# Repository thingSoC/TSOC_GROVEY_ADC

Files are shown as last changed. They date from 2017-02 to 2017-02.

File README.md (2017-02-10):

# TSOC_GROVEY_ADC - thingSoC ADS1115/ADS1015 ADC Module :

**TSOC_GROVEY_ADC** is a four(4) port Analog-to-Digital converter board, an Embedded Module for thingSoC.

The **TSOC_GROVEY_ADC** can operate at either 3.3V or 5V, and can also level translate 3.3V processor bus to 5V Analog peripherals when needed.

The **TSOC_GROVEY_ADC** allows you to connect [thingSoC](http://thingsoc.github.io/), [Mikrobus](http://www.mikroe.com/mikrobus/), 
and/or [Grove System](http://www.seeedstudio.com/blog/2016/03/09/tutorial-intro-to-grove-connectors-for-arduinoraspberry-pi-projects/) 
Modules all at the same time, with any processor module.
This gives you maximum flexiblity for sensor and actuator selection, and reuse. 
When populated with the ADS1115 device it provides 16 bit ADC conversion, and when populated with the ADS1015 device provides 12 bit ADC conversion.

The thingSoC "Grovey Series" was designed as "Everyday Electronics", a no-frills, low cost, approach to modular embedded product design.
thingSoC boards are similar in size to most break-out-boards (BOBs), but feature a standardized stacking pinout, as well as an I2C metadata store (EEPROM)
to indicate what peripherals are installed.

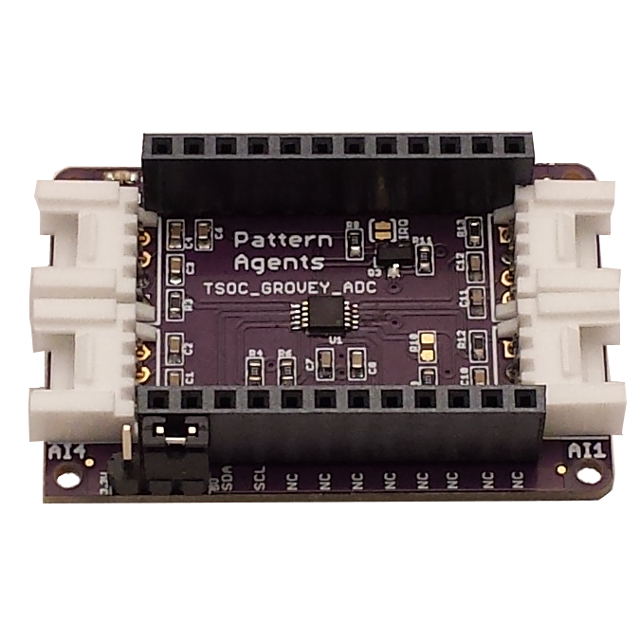
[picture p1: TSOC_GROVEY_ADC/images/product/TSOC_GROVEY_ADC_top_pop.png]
thingSoC TSOC_GROVEY_ADC
[TSOC_GROVEY_ADC](https://github.com/thingSoC/TSOC_GROVEY_ADC)

---------------------------------------

## TSOC_GROVEY_ADC Status <a name="TSOC_GROVEY_ADC_status"/>

**11/06/2016:** 
Revision 1.0 - Initial Layout released to OSHpark

**01/10/2017:**
Revison 2.0 - released to OSHpark

---------------------------------------
## TSOC_GROVEY_ADC Model Images

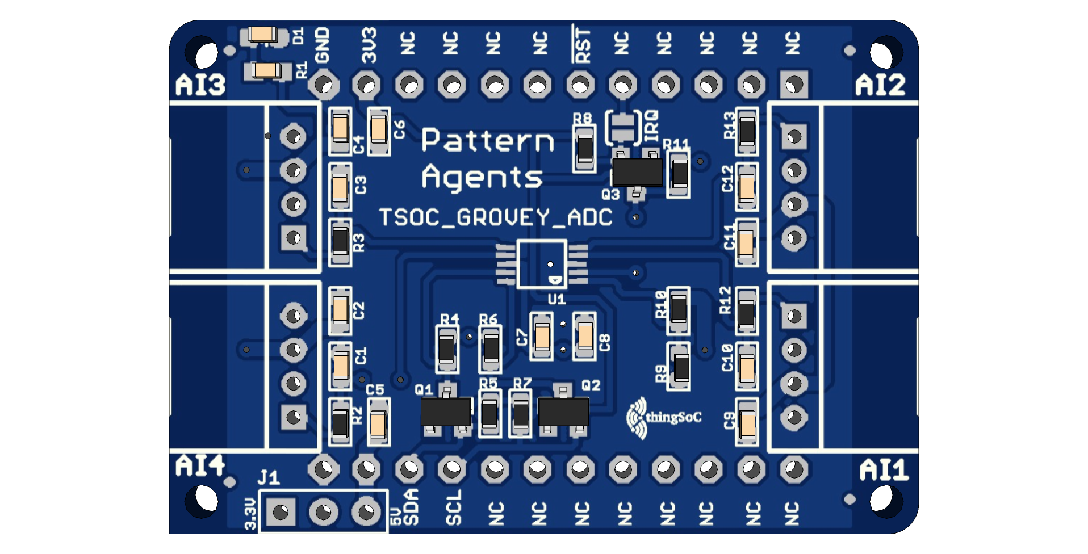
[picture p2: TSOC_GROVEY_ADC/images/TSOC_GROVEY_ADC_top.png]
thingSoC TSOC_GROVEY_ADC
[TSOC_GROVEY_ADC](https://github.com/thingSoC/TSOC_GROVEY_ADC)

[thingSoC TSOC_GROVEY_ADCTSOC_GROVEY_ADC](https://github.com/thingSoC/TSOC_GROVEY_ADC)

---------------------------------------

## TSOC_GROVEY_ADC Documentation Index <a name="TSOC_GROVEY_ADC_documentation_index"/>

[TSOC_GROVEY_ADC Project](http://thingsoc.github.io/projects/TSOC_GROVEY_ADC.html)

[TSOC_GROVEY_ADC Hardware](https://github.com/thingSoC/TSOC_GROVEY_ADC/tree/master/TSOC_GROVEY_ADC/hardware)

---------------------------------------

## thingSoC Documentation Index <a name="thingSoC_documentation_index"/>

[thingSoC Organization Website](http://thingSoC.github.io)

[thingSoC FAQ - Frequently Asked Questions](http://thingsoc.github.io/support/faq.html)

---------------------------------------

[thingSoC 
*thingSoC*](http://thingsoc.github.io)

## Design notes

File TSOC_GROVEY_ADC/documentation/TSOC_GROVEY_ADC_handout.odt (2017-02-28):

thingSoC GROVEY_ADC Board

Thank you for purchasing a TSOC_GROVEY_ADC board!
Please see the Getting Started Guide at :
https://github.com/thingSoC/TSOC_GROVEY_ADC (https://github.com/thingSoC/TSOC_NEOLED)
It has complete instructions and examples to download.

thingSoC GROVEY_ADC Board

Thank you for purchasing a TSOC_GROVEY_ADC board!
Please see the Getting Started Guide at :
https://github.com/thingSoC/TSOC_GROVEY_ADC (https://github.com/thingSoC/TSOC_NEOLED)
It has complete instructions and examples to download.

thingSoC GROVEY_ADC Board

Thank you for purchasing a TSOC_GROVEY_ADC board!
Please see the Getting Started Guide at :
https://github.com/thingSoC/TSOC_GROVEY_ADC (https://github.com/thingSoC/TSOC_NEOLED)
It has complete instructions and examples to download.

thingSoC GROVEY_ADC Board

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

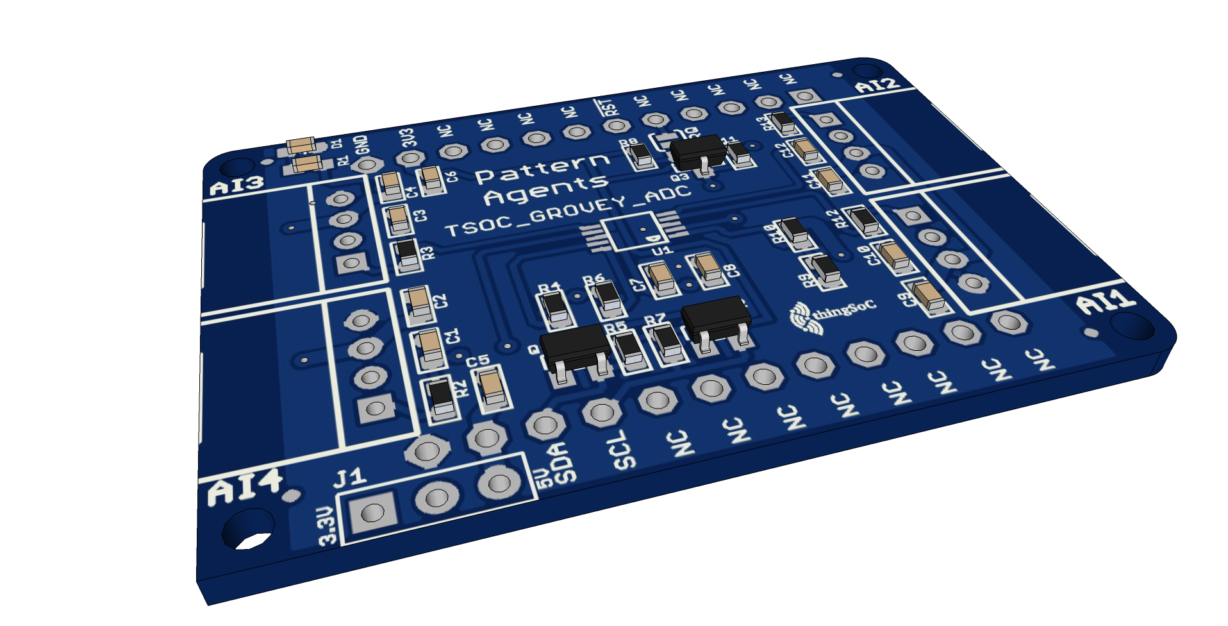
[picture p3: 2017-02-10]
TSOC_GROVEY_ADC/images/TSOC_GROVEY_ADC_iso_raw.png

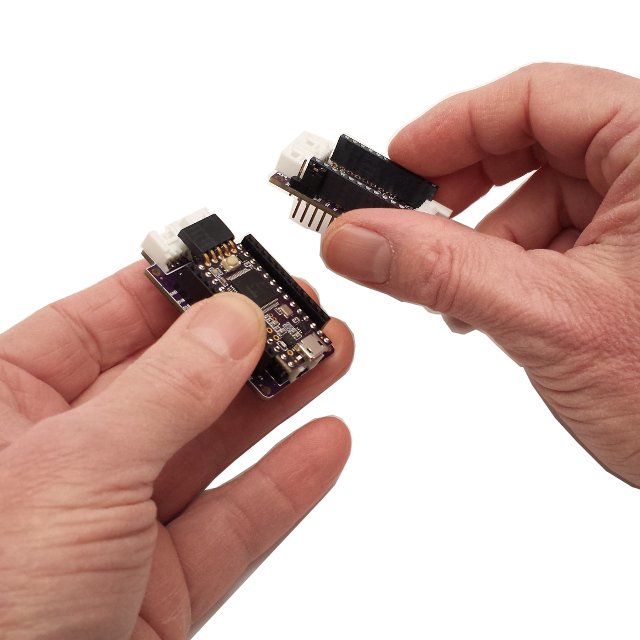
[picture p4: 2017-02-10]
TSOC_GROVEY_ADC/images/product/TSOC_GROVEY_ADC_hand.jpg

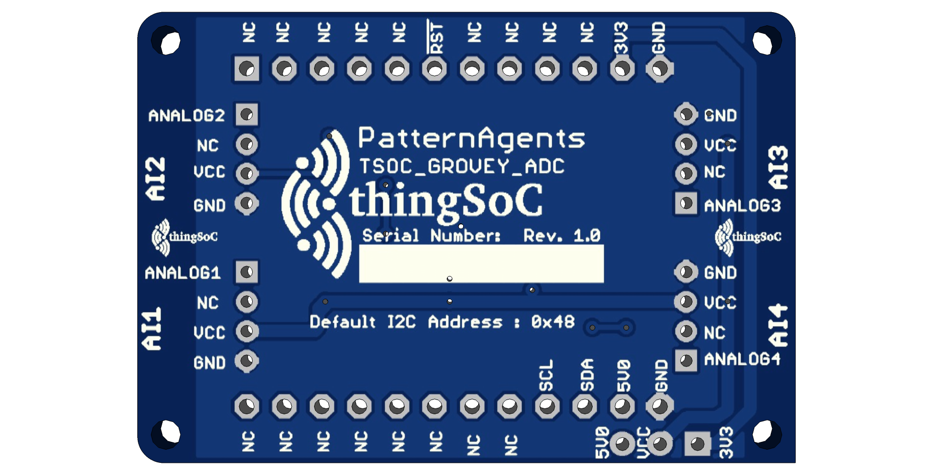
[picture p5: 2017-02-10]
TSOC_GROVEY_ADC/images/TSOC_GROVEY_ADC_bot_raw.png

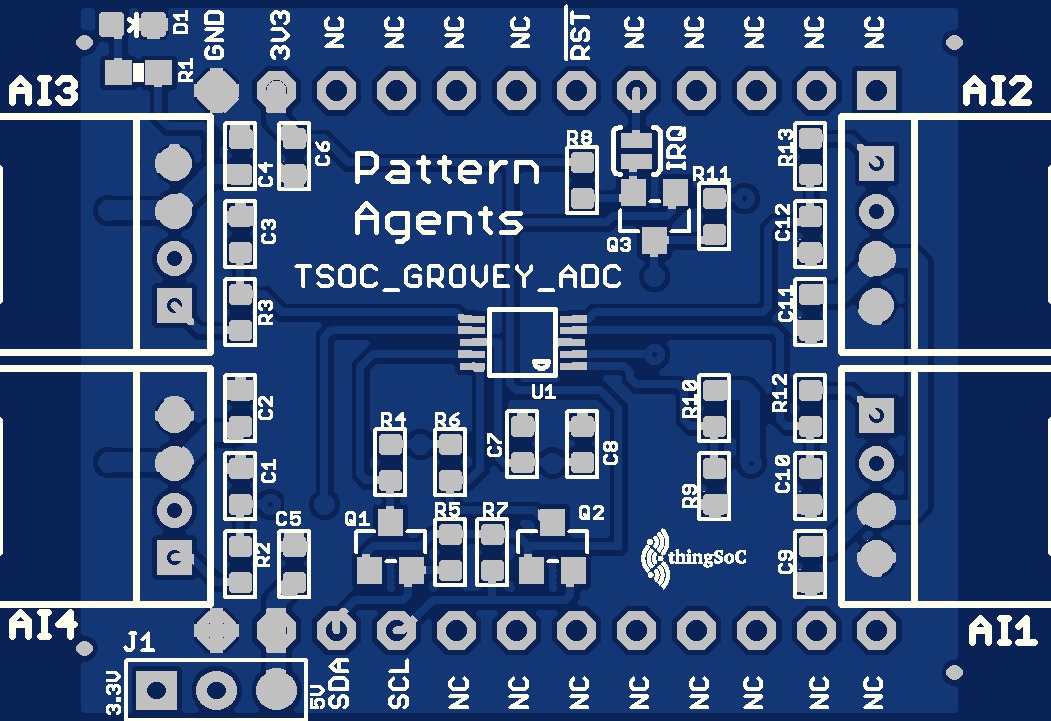
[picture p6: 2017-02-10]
TSOC_GROVEY_ADC/eagleUp/eagleUp_TSOC_GROVEY_ADC_board_top.jpg

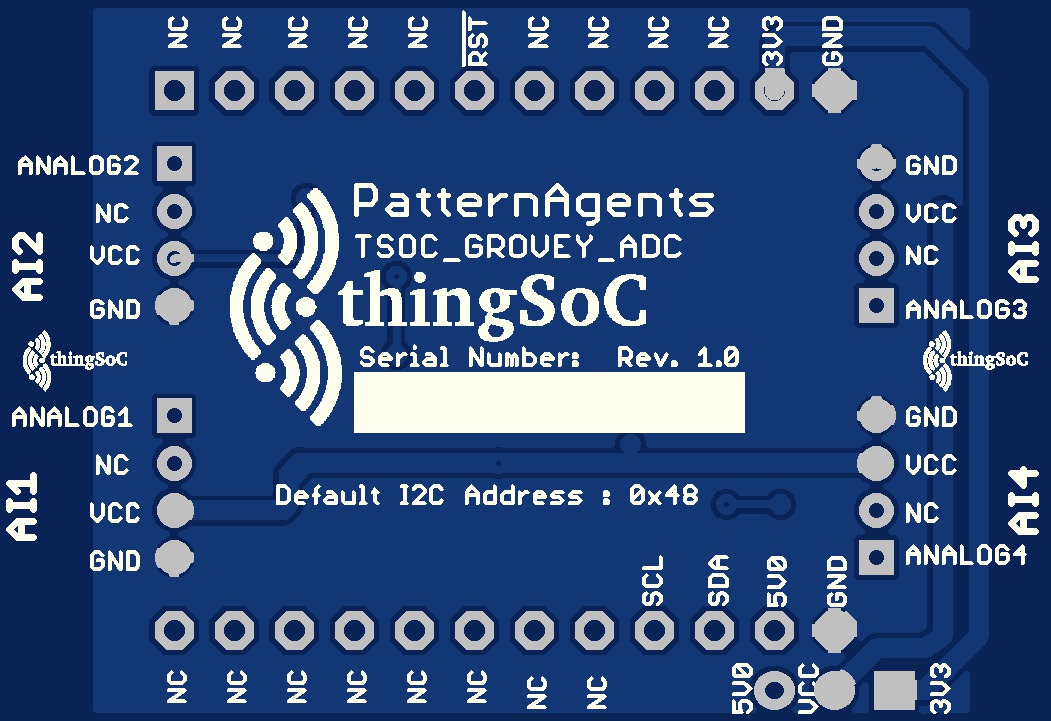
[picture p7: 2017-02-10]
TSOC_GROVEY_ADC/eagleUp/eagleUp_TSOC_GROVEY_ADC_board_bottom.jpg

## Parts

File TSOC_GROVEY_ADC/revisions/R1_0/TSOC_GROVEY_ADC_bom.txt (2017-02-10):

Partlist exported from 
U:/PatternAgents/eagle/TSOC_Modules/TSOC_GROVEY_ADC/TSOC_GROVEY_ADC/revisions/R1_0/TSOC_GROVEY_ADC.sch at 1/29/2017 11:52:49 AM

Qty Value             Device                             Package         Parts                       Description                                          
1   RED               LED0603                            LED-0603        D1                          LEDs                                                 
1   ADS1115IDGST      ADC_ADS1015                        MSOP10          U1                          ADS1015 12-bit 4-Channel I2C ADC
3   BSS138W-7-F       SMD-MOSFET-N-CH-50V-200MA-BSS138W  SOT-23          Q1, Q2, Q3                  305030000                                            
1   1K                RESISTOR_SFE0603-RES               0603-RES        R1                          Resistor                                             
7   10K 1/10W         SMD-RES-10K-5%-1/10W(0603)         R0603           R4, R5, R6, R7, R8, R9, R11 301010293                                            
4   390K              SMD-RES-150K-1%-1/10W(0603)        R0603           R2, R3, R12, R13            301010205                                            
5   100nf             CERAMIC-100NF-50V-10%-X7R(0603)    C0603           C2, C4, C7, C9, C11         302010138                                            
4   1nf               CERAMIC-1NF-50V-5%-C0G(0603)       C0603           C1, C3, C10, C12            302010341                                            
3   1uf               CERAMIC-1UF-25V-10%-X7R(0603)      C0603           C5, C6, C8                  302010139                                            
1   3p-2.54           DIP-BLACK-MALE-HEADER-VERT         H3-2.54         J1                          320020079                                            
4   4P-2.0-90D        GROVE-CONNECTOR-DIP-90D(4P-2.0)    HW4-2.0-90D     AI1, AI2, AI3, AI4          320110034                                            
1                     JMP-2-NO                           JMP-2-NO        IRQ                         Two Terminal Jumper - Normally Open
----------------------------------------------------------------------------
1   DNP               SMD-RES-10K-5%-1/10W(0603)         R0603           R10                         301010293

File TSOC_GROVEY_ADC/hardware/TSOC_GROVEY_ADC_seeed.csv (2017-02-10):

Part/Designator | Manufacture Part Number/Seeed SKU | Quantity
C1, C2, C3, C4, C6, C7 | 302010138 | 6
R8, R9, R10, R11 | 301010299 | 4
R1 | 301010298 | 1
R2, R3, R4, R5, R6, R7, R12, R13, R14, R15 | 301010124 | 10
C5 | 302010013 | 1
I2C1, I2C2, I2C3, I2C4 | 320110034 | 4
J1 | 320020079 | 1
U1 | ADS1115IDGSR | 1
D1 | 304090043 | 1

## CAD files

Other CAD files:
TSOC_GROVEY_ADC/eagleUp/TSOC_GROVEY_ADC.skp

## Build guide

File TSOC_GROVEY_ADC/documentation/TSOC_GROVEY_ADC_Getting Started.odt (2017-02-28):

Welcome to the thingSoC® Grovey ADC

The TSOC_GROVEY_ADC is a four(4) port Analog-to-Digital converter, based on the ADS1015/1115 chip, in an Embedded Module format for the new thingSoC, Internet of Things open source hardware standard.

Getting Started :
The TSOC_GROVEY_ADC provides four (4) Analog-to-Digital ports on four(4) Grove compatible connectors. You can use the TSOC_GROVEY_ADC when :

1. When you need to do input 5.0 Volt level sensors to a 3.3V processor.
2. When you need more resolution than the 3.3V processor can provide.
3. When you need anti-aliasing input conditioning on your analog inputs.

The TSOC_GROVEY_ADC is an open source hardware project from PatternAgents, LLC,
and you are free to download the schematics, layouts, gerbers, BOMs, etc and build your own boards if you wish.

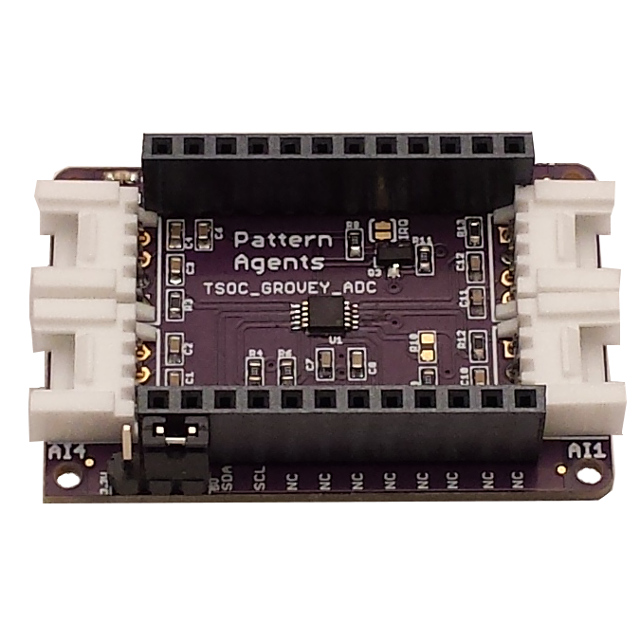
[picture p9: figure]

Safe Handling Precautions :

1) Always remove/unplug all power before inserting or removing peripherals.
2) Always ground yourself by touching a ground point before handling your boards.
3) Use a static safe bag when transporting your TSOC_GROVEY_ADC board.

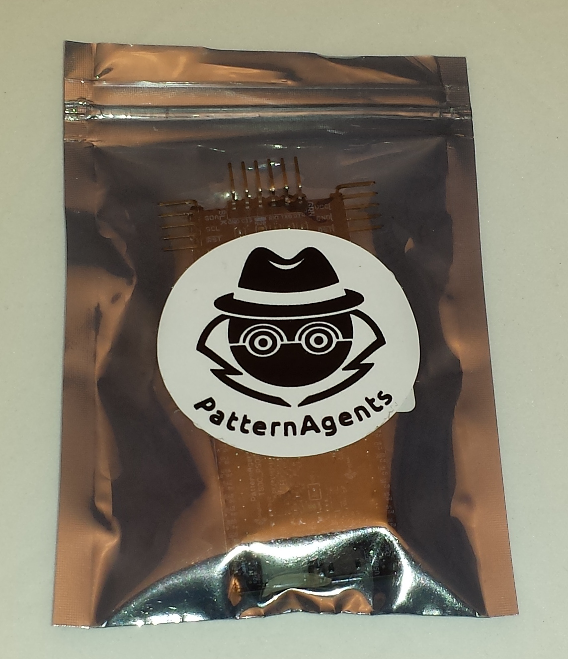
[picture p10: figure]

Adding Grove Peripherals :
The TSOC_GROVEY_ADC board supports Grove peripherals.
1) Grove connectors are polarized, and can only be plugged in one way.


Adding Mikrobus Peripherals :
The TSOC_GROVEY_ADC board supports Grove peripherals and can interoperate with Mikrobus peripherals.

1) Make sure to align the SQUARE/CUT edges of the Mikrobus board together to insure that
the polarity is correct. Push down evenly to seat the boards in the socket.

2) Note that the "stacking pins" are somewhat longer by design, and there will be some
extra space between the boards when using stacking connectors.

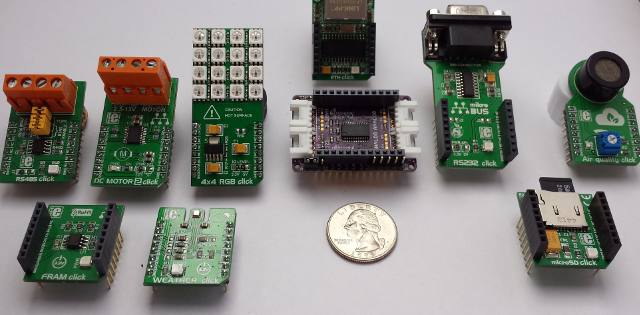
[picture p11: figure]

For more information and examples :

Complete documentation, including schematics, layouts, gerbers, and Bill of Materials (BOM) are available on the thingSoC website at :

https://github.com/thingSoC/TSOC_GROVEY_ADC/tree/master/TSOC_GROVEY_ADC (https://github.com/thingSoC/TSOC_PSoC4L/tree/master/TSOC_PSoC4L)

There is also a project Wiki available for asking questions and more information at :

https://github.com/thingSoC/TSOC_GROVEY_ADC/wiki (https://github.com/thingSoC/TSOC_PSoC4L/wiki)

thingSoC® Grovey ADC Features :

The TSOC_GROVEY_ADC is a low cost, embeddable module featuring an NXP PCA9546A device :

- ADS1015 (12 bits) or ADS1115 (16 bits)
- 0 Hz to 400KHz I2C Bus Speed
- 3.3 Volt or 5.0 Volt operation
- Optional Active Low Reset Line
- Low Standby current
- Builtin ESD protection
- ADC (4 Channels)
- Power LED
- thingSoC Compliant Module
- Mikrobus Compatible Module (http://www.mikroe.com/mikrobus/)
- Support SeeedStudio Grove Peripherals

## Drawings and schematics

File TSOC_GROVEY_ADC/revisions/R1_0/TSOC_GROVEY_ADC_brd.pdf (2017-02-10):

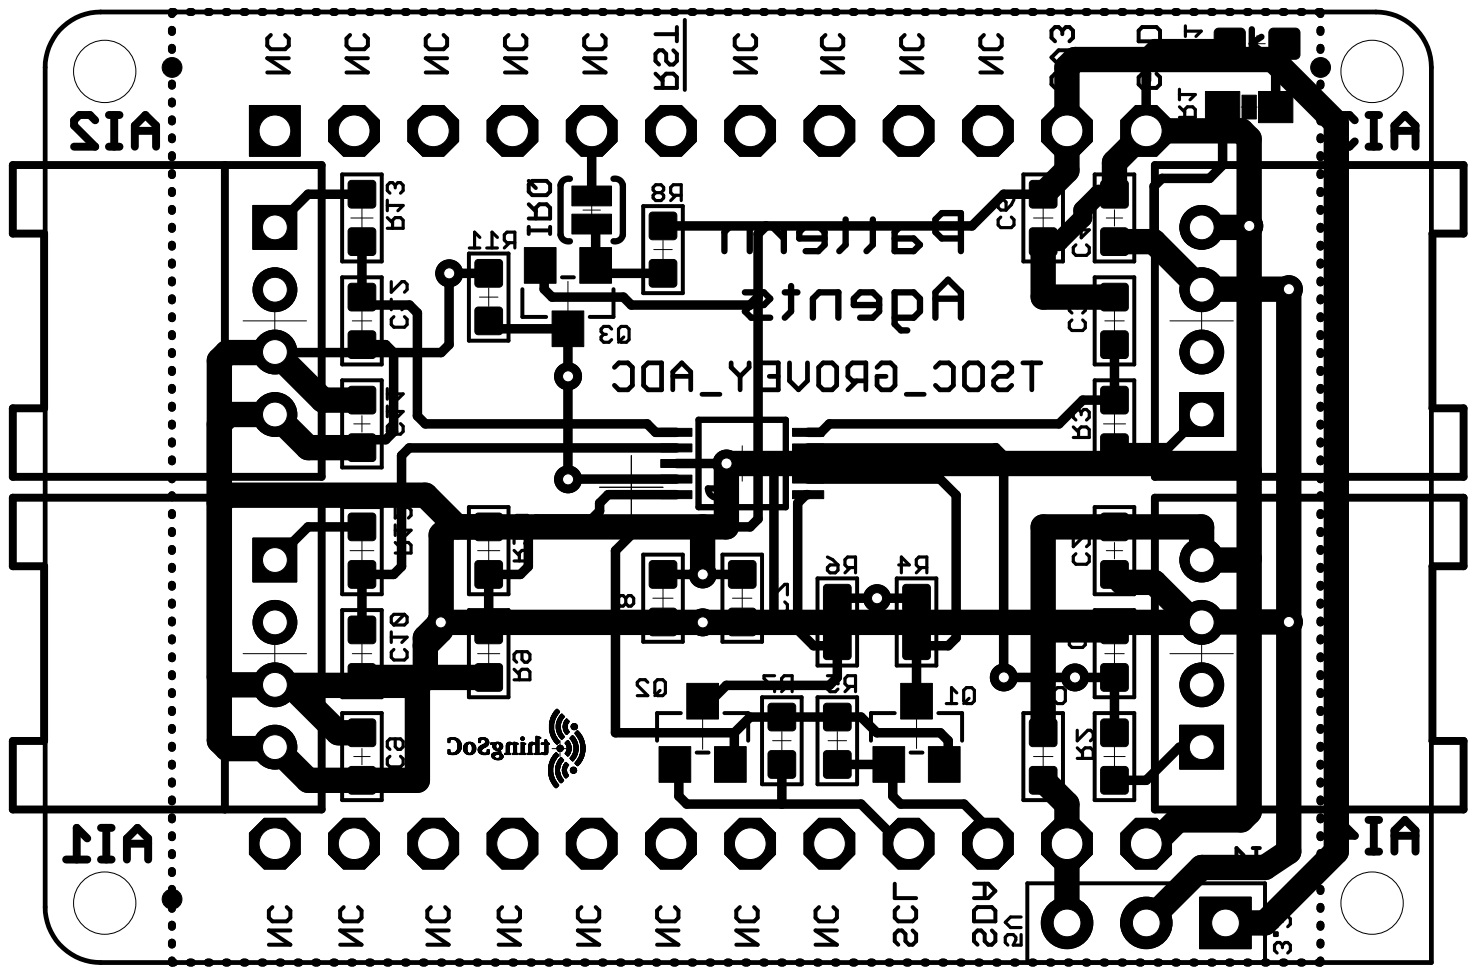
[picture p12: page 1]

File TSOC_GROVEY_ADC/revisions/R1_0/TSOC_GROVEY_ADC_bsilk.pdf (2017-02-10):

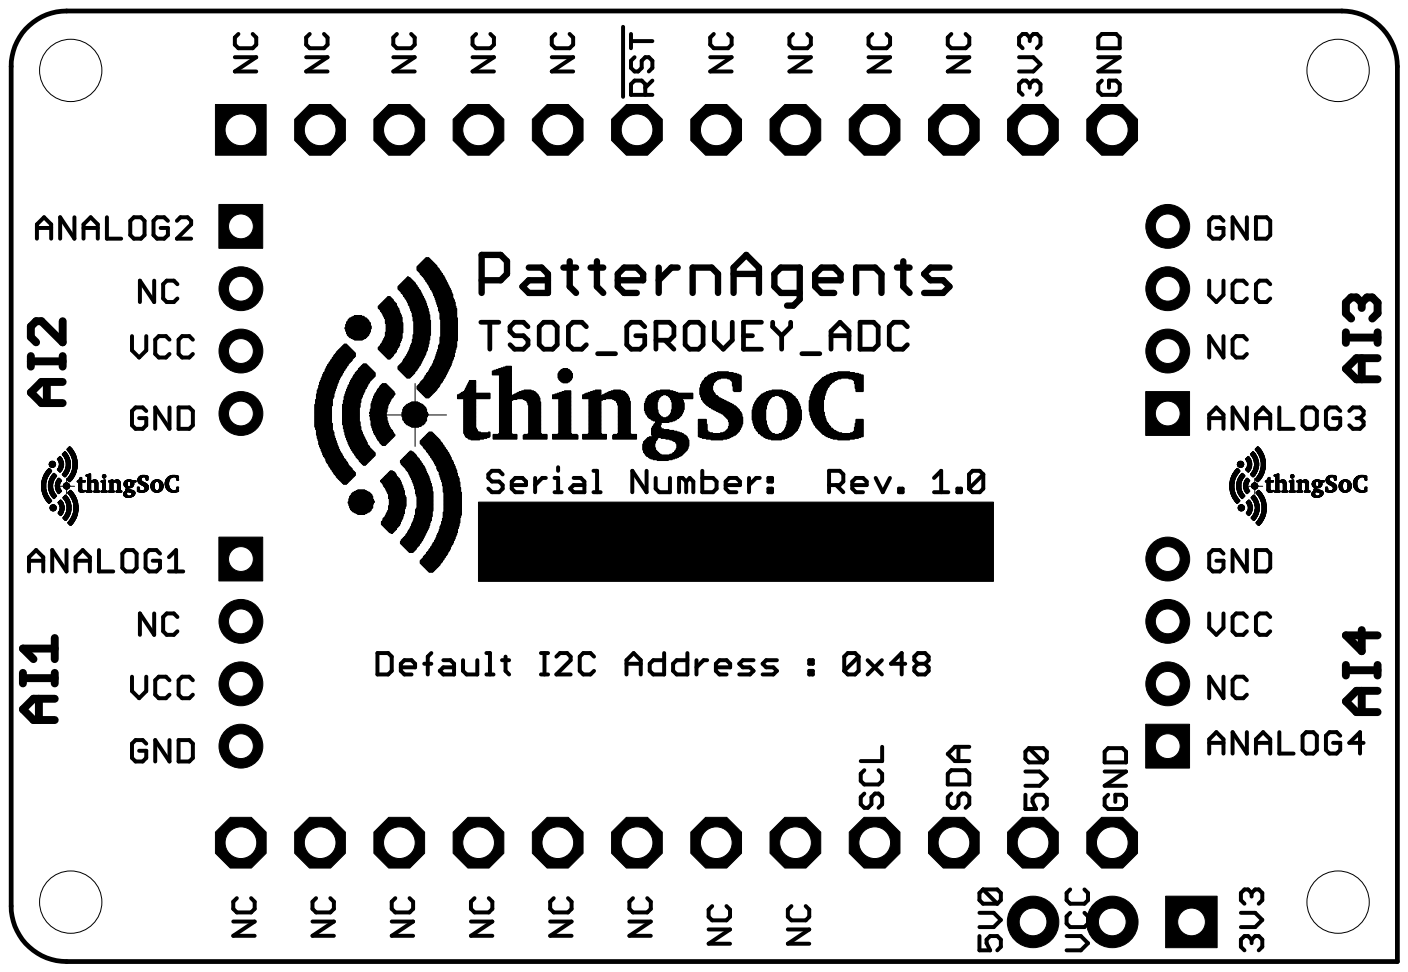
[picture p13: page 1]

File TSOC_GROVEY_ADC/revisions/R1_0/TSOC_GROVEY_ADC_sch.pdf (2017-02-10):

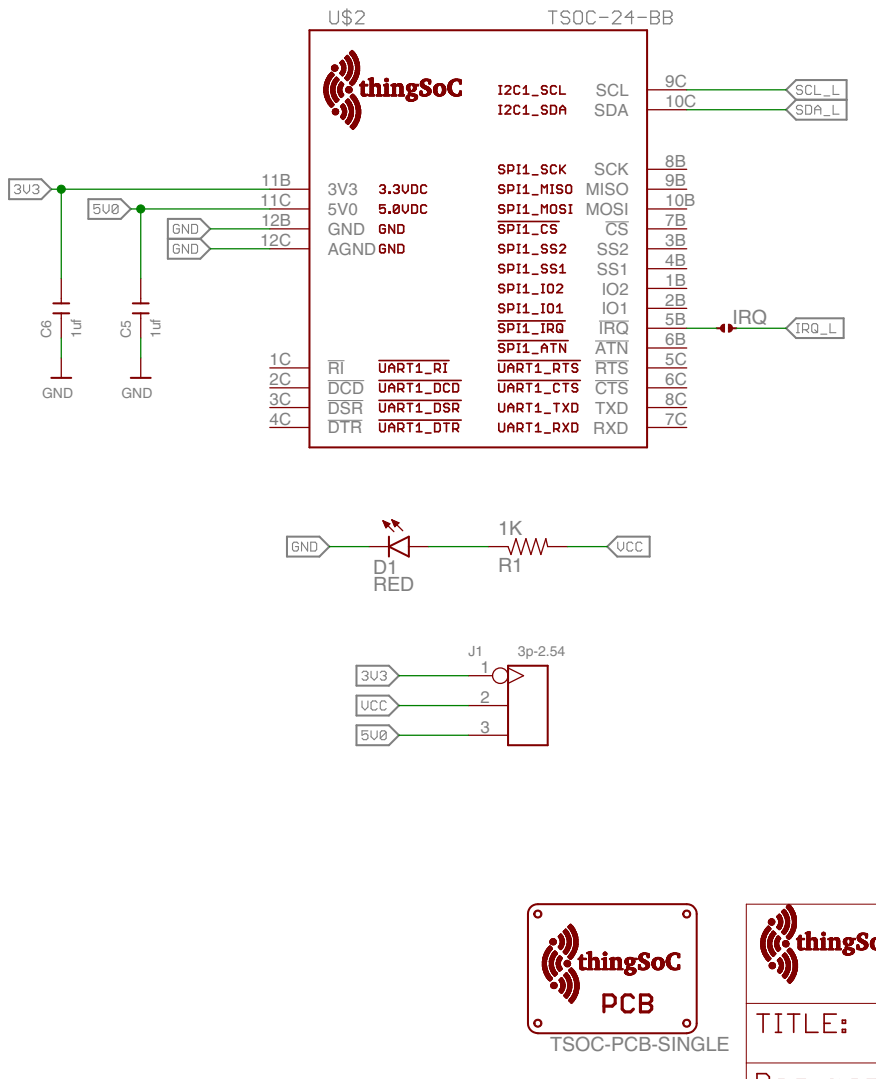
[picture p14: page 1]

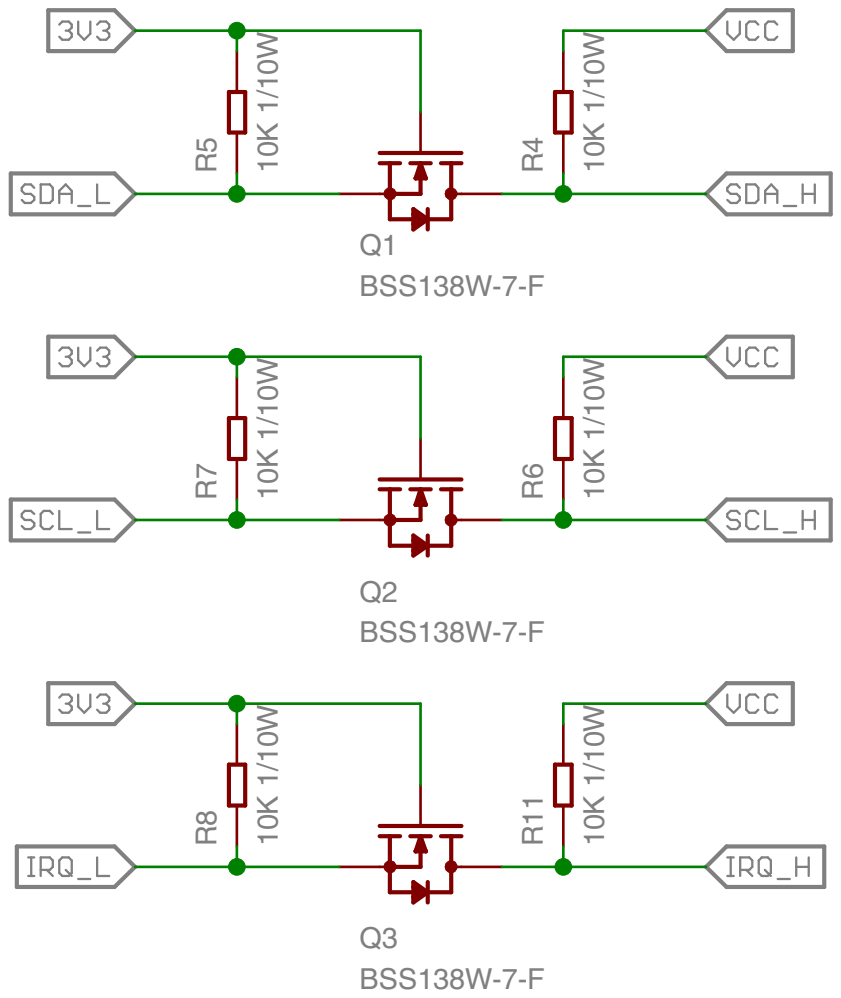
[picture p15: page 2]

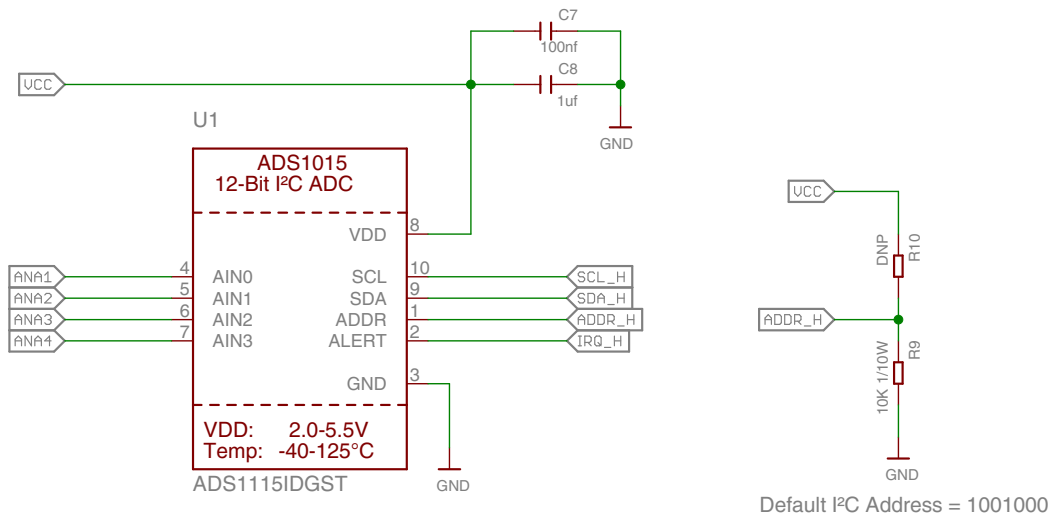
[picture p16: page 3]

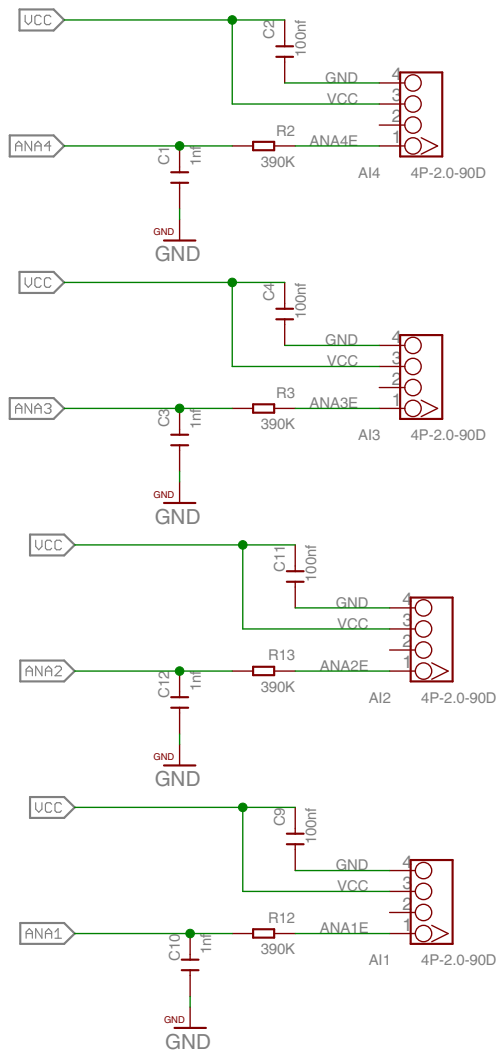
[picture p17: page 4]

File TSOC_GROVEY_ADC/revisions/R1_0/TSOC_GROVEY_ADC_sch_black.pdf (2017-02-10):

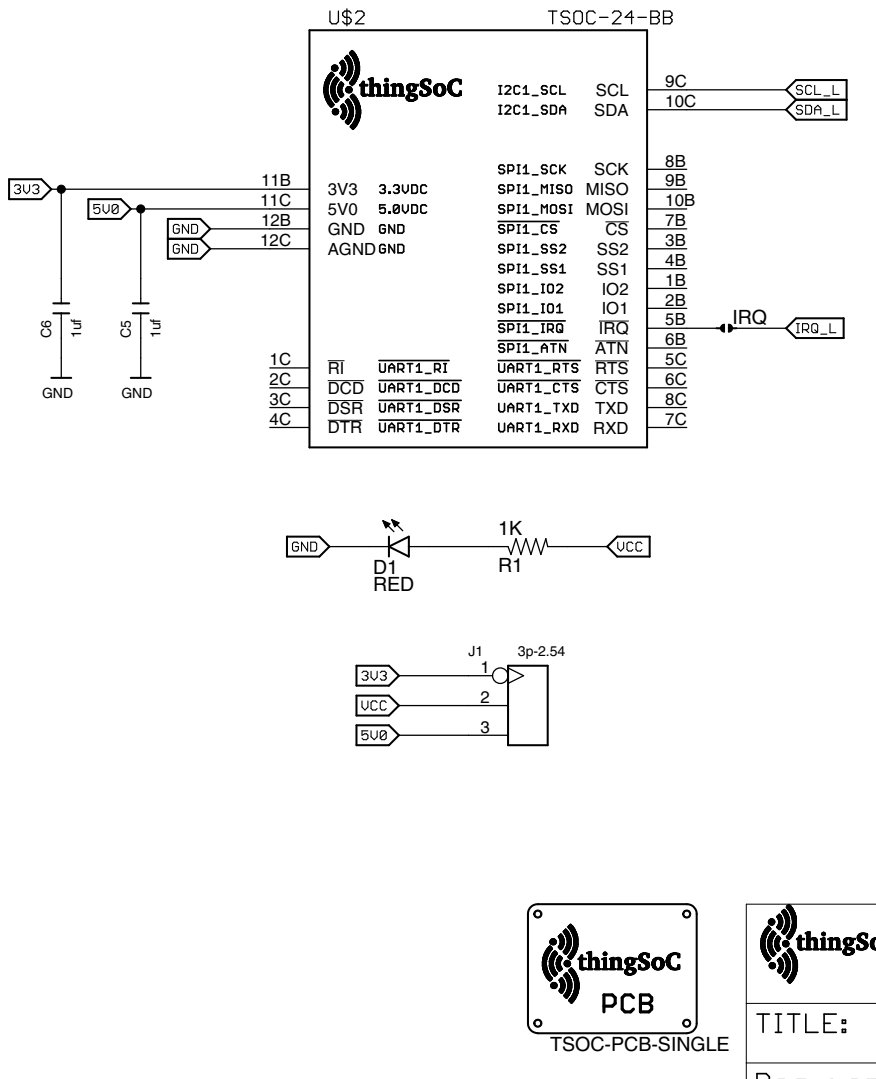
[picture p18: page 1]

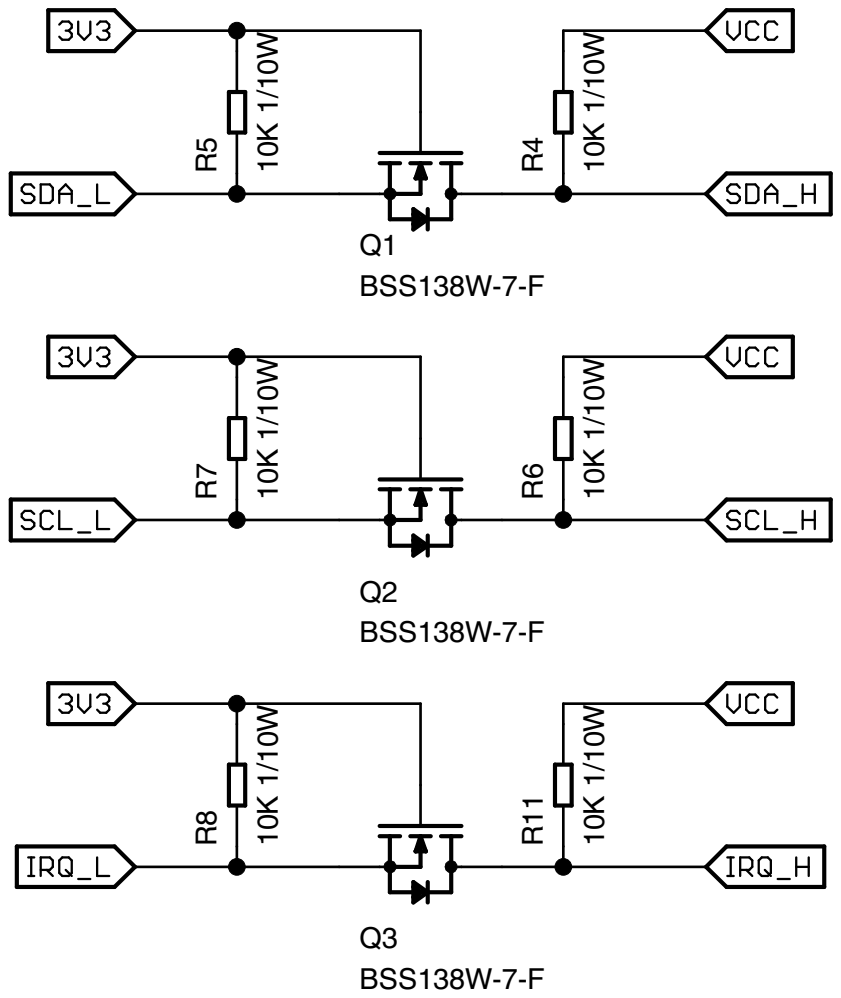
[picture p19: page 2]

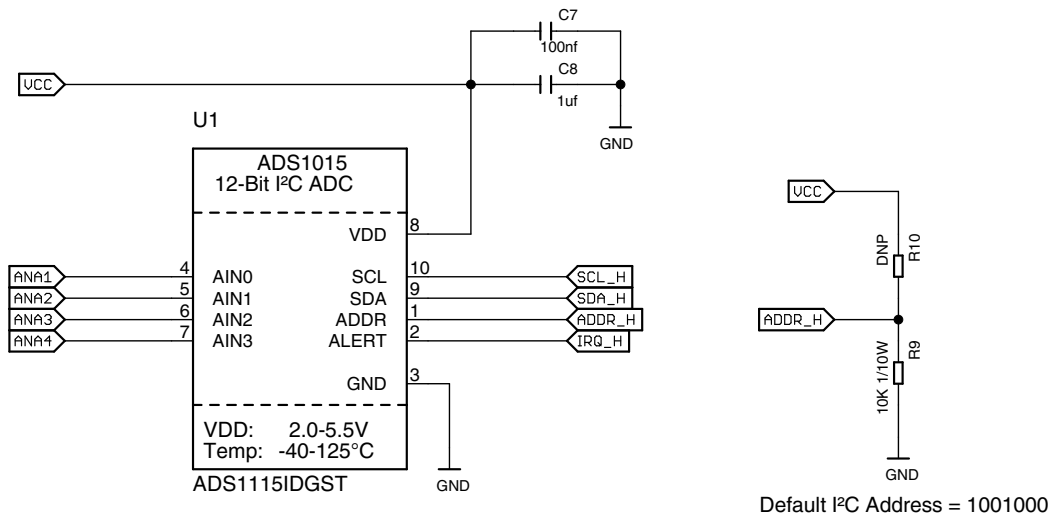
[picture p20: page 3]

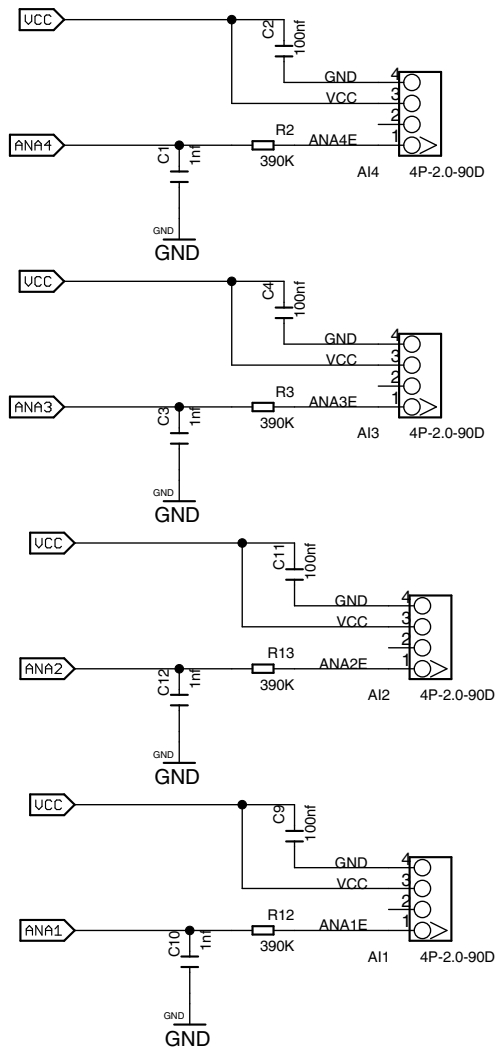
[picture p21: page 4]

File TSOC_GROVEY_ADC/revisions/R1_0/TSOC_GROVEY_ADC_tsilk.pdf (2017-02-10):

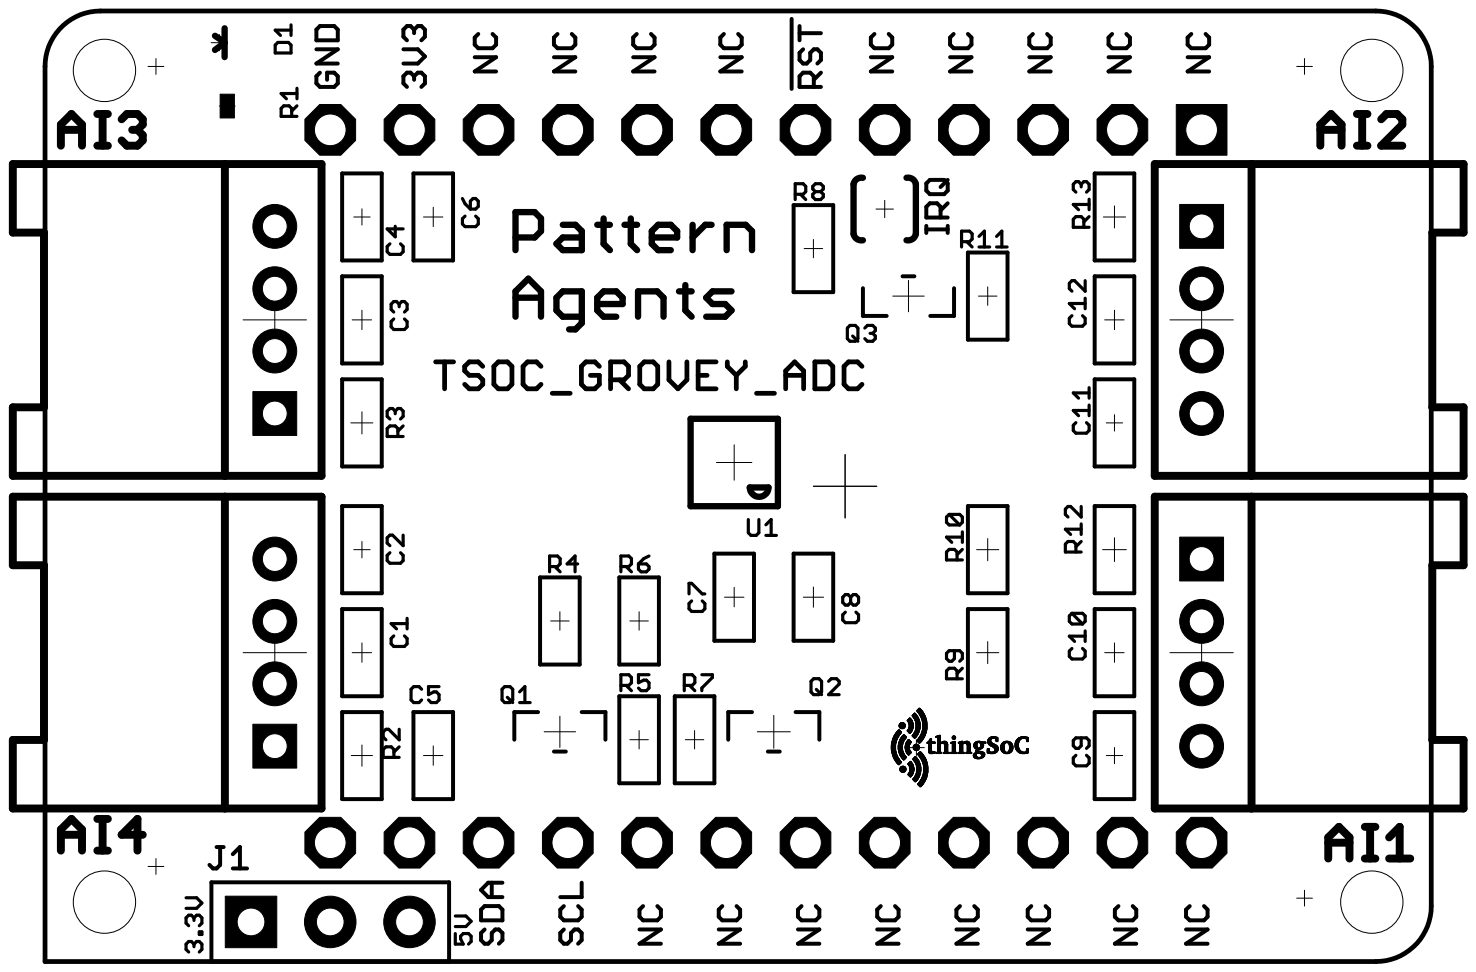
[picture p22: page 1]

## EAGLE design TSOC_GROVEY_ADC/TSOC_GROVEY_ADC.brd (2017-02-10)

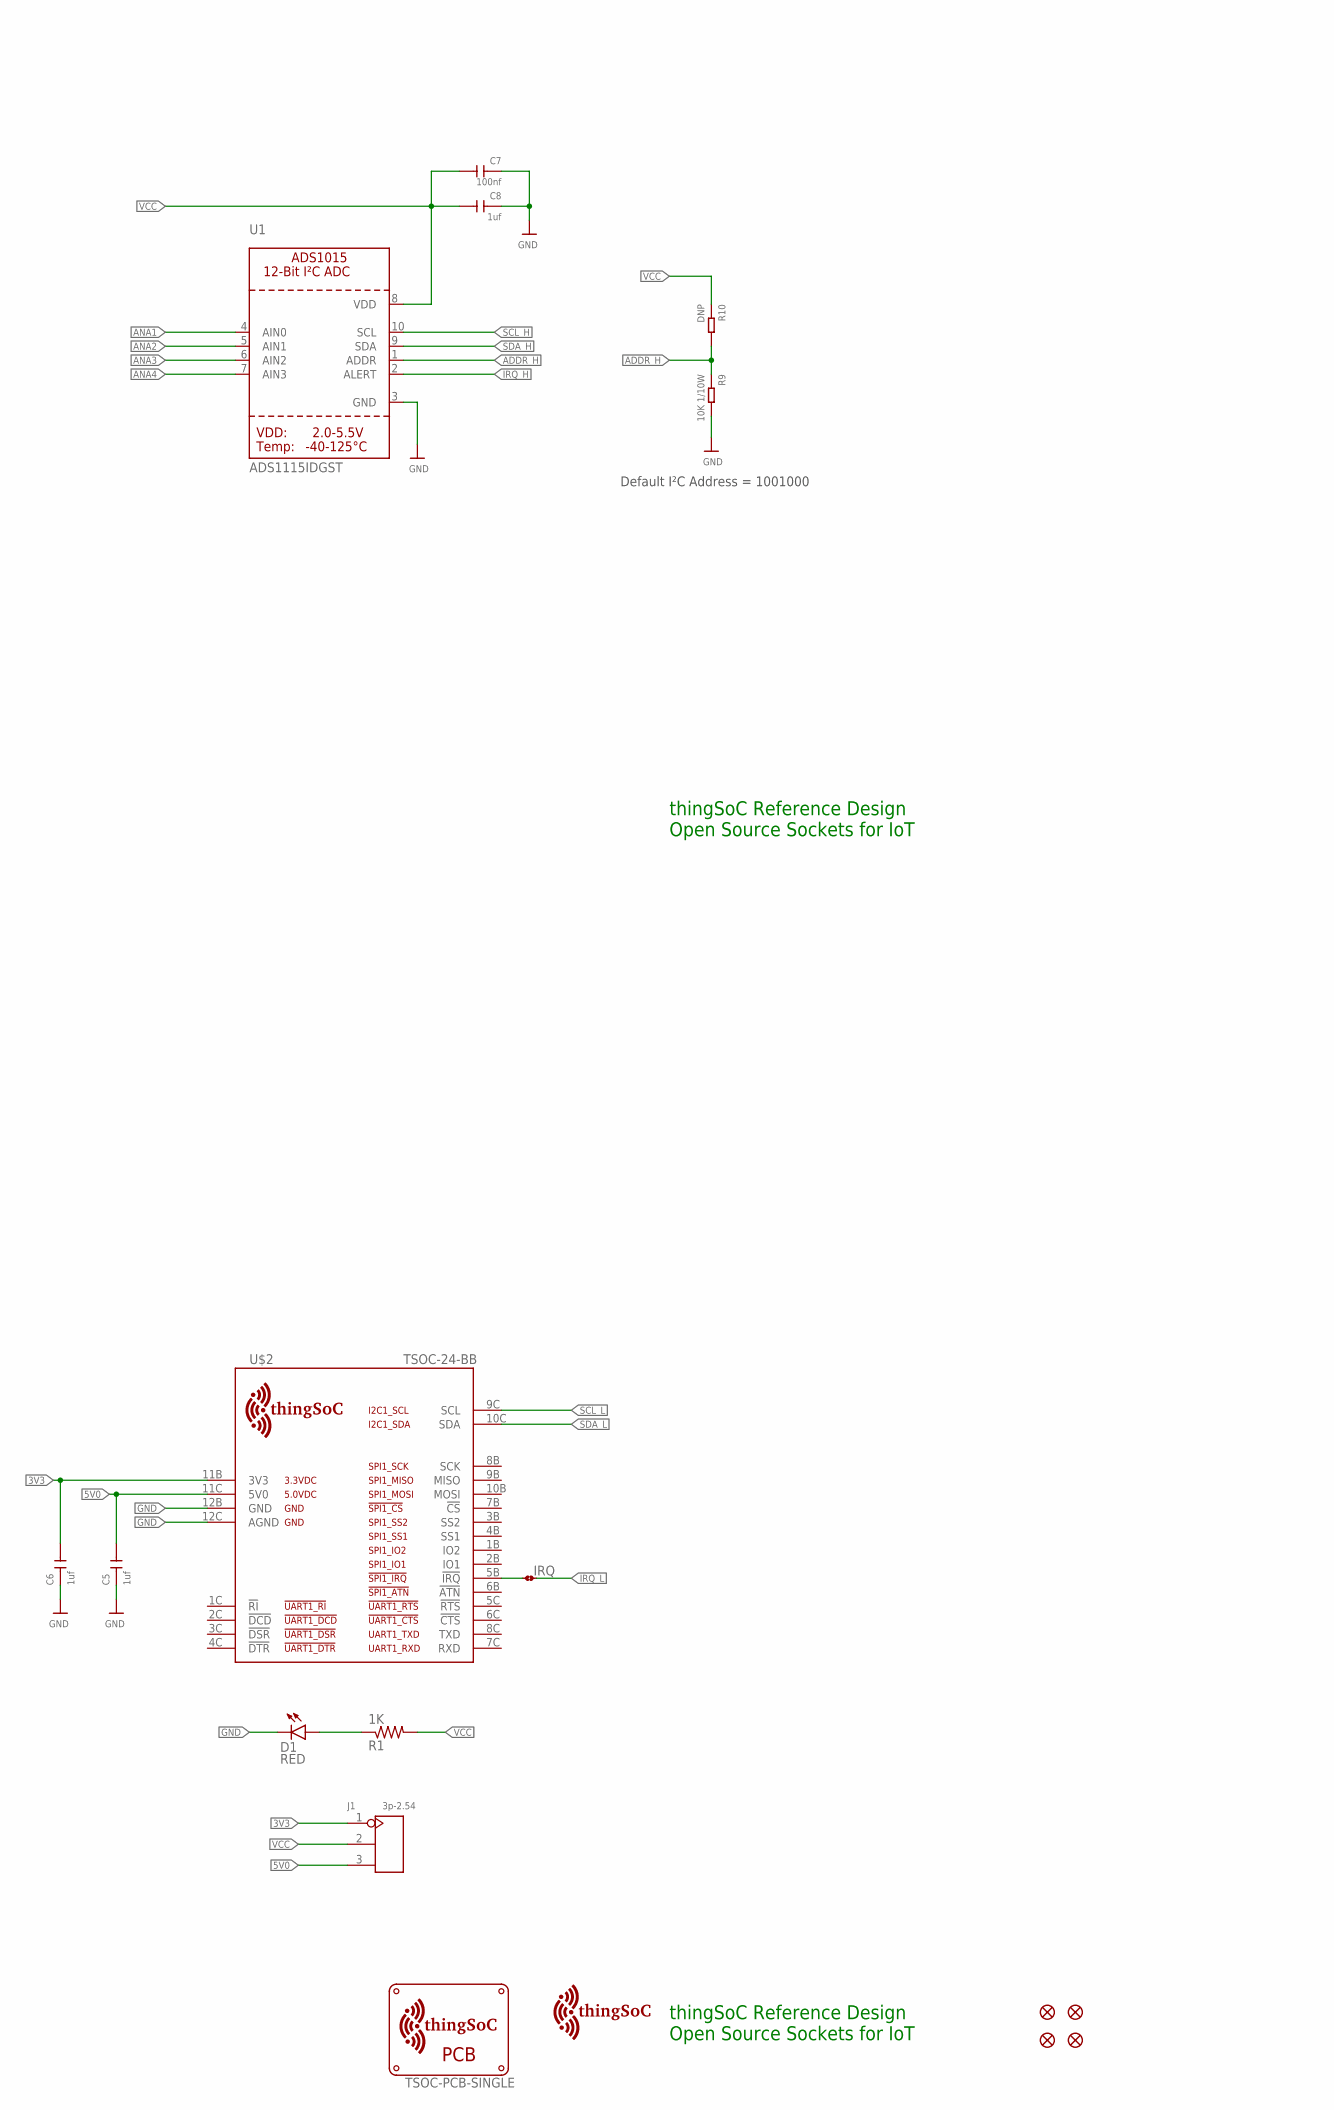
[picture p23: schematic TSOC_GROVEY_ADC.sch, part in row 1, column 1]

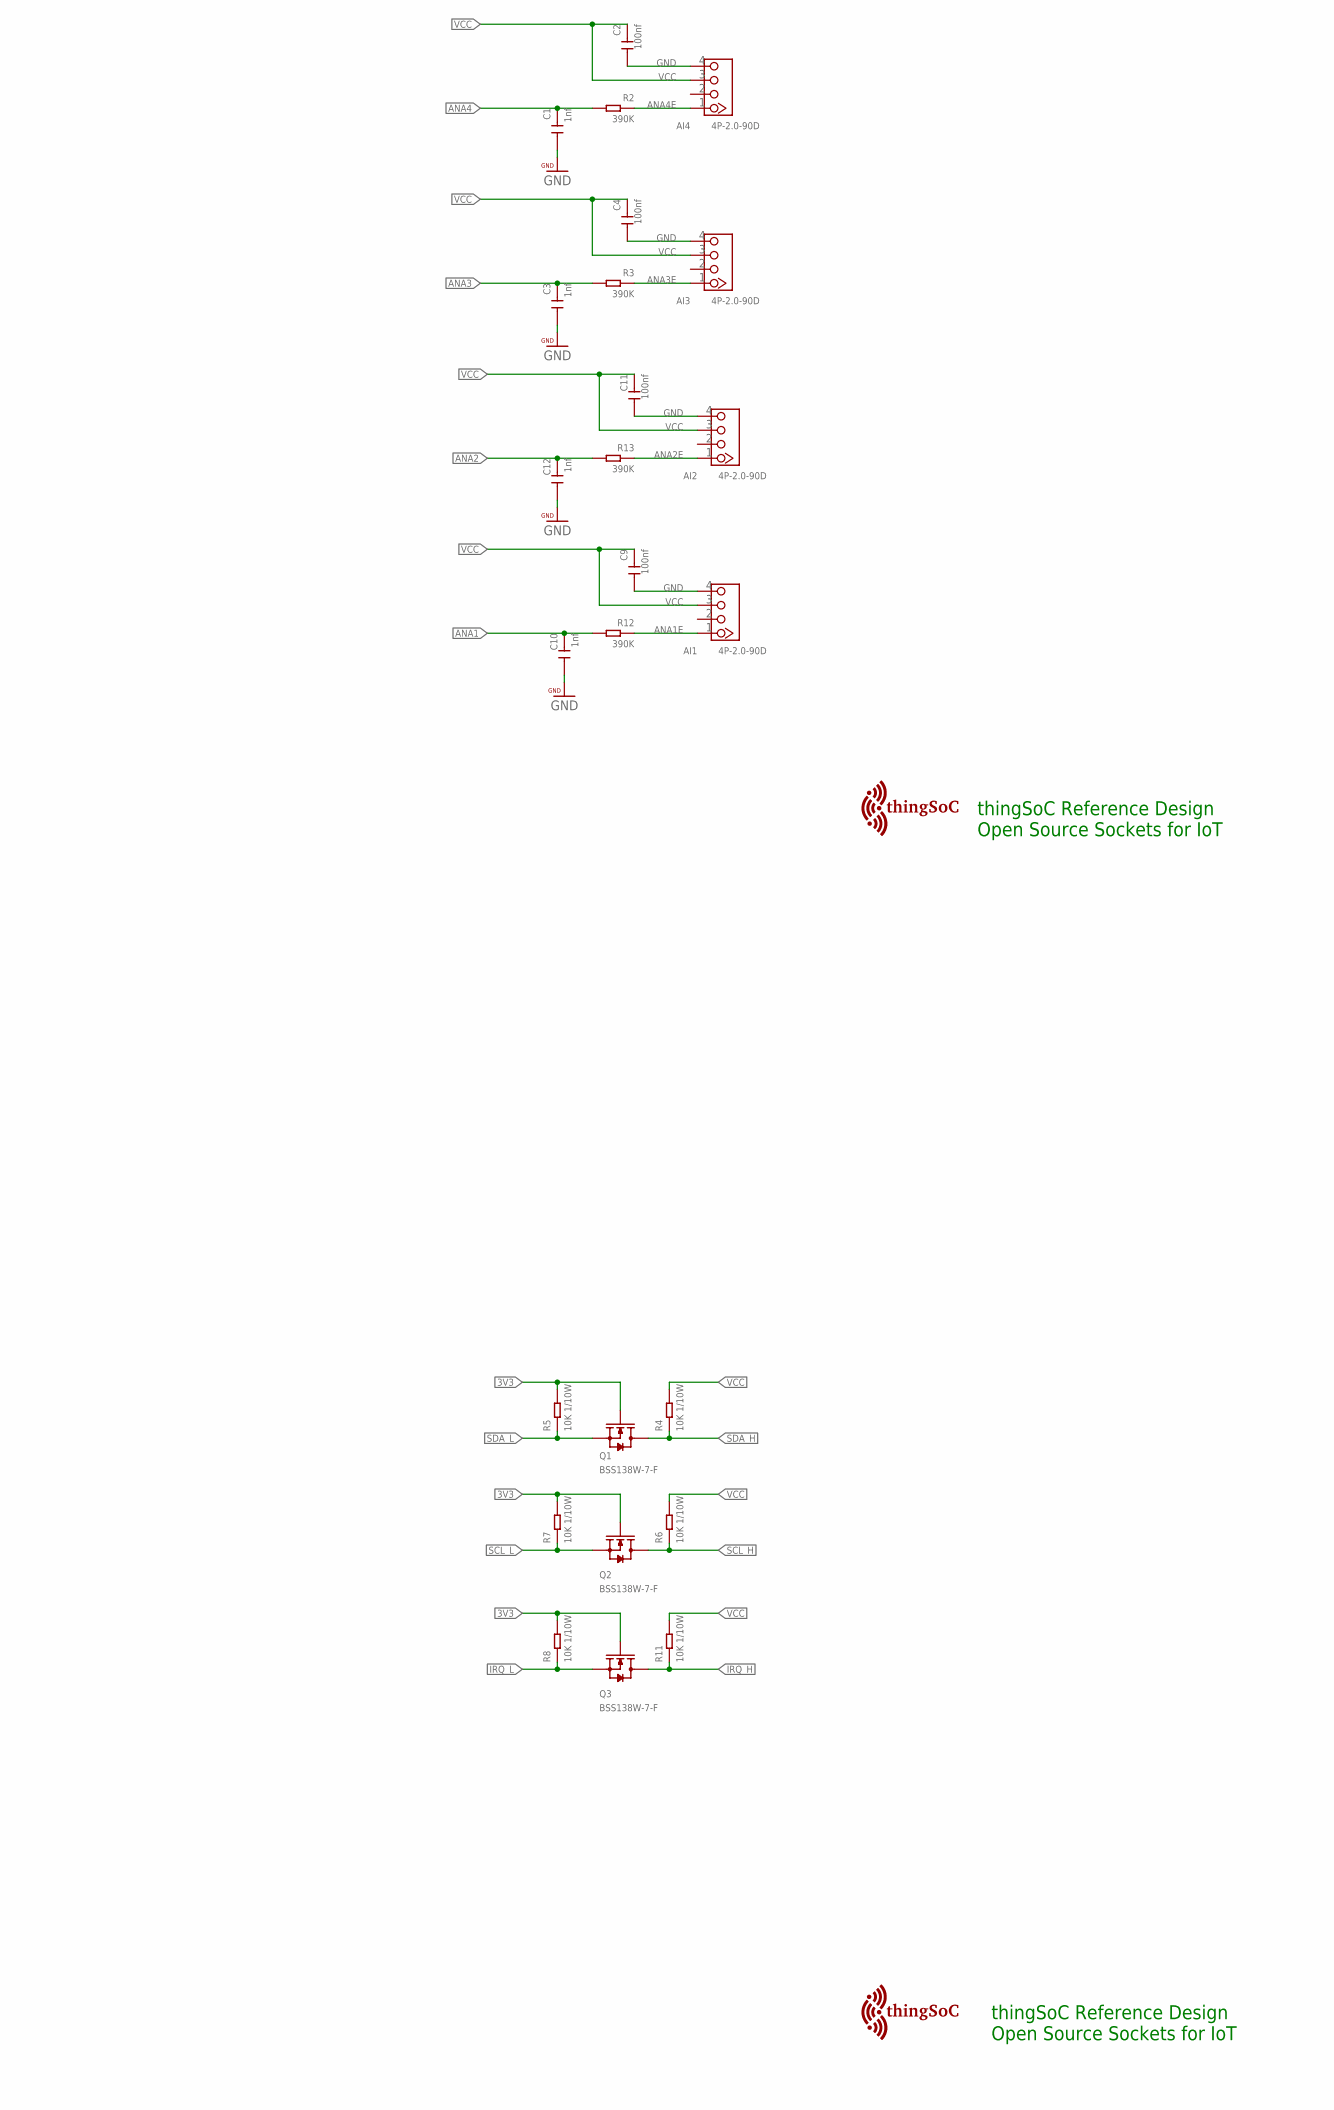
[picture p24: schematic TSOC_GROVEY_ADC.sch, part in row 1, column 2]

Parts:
AI1, AI2, AI3, AI4: 4P-2.0-90D; HW4-2.0-90D
C1, C3, C10, C12: 1nf; C0603
C2, C4, C7, C9, C11: 100nf; C0603
C5, C6, C8: 1uf; C0603
D1: RED; LED-0603
FID1, FID2, FID3, FID4: FIDUCIALUFIDUCIAL; MICRO-FIDUCIAL
IRQ: JMP-2-NO
J1: 3p-2.54; H3-2.54
Q1, Q2, Q3: BSS138W-7-F; SOT-23
R1: 1K; 0603-RES
R2, R3, R12, R13: 390K; R0603
R4, R5, R6, R7, R8, R9, R11: 10K 1/10W; R0603
R10: DNP; R0603
U1: ADS1115IDGST; MSOP10
U$1: TSOC-PCB-SINGLE; TSOC-BB-BRD-DIM
U$2: TSOC-24-BB; TSOC-BB-S24
U$100, U$103: TSOC-LOGO-SMALL; TSOC-LOGO-SML
U$102: TSOC-LOGO-LRG

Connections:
3V3: C6.2, J1.1, Q1.1 (G), Q2.1 (G), Q3.1 (G), R5.2, R7.2, R8.2, U$2.11B (3V3)
5V0: C5.2, J1.3, U$2.11C (5V0)
ADDR_H: R9.1, R10.2, U1.1 (ADDR)
ANA1: C10.1, R12.2, U1.4 (AIN0)
ANA1E: AI1.1, R12.1
ANA2: C12.1, R13.2, U1.5 (AIN1)
ANA2E: AI2.1, R13.1
ANA3: C3.1, R3.2, U1.6 (AIN2)
ANA3E: AI3.1, R3.1
ANA4: C1.1, R2.2, U1.7 (AIN3)
ANA4E: AI4.1, R2.1
GND: AI1.4, AI2.4, AI3.4, AI4.4, C1.2, C2.2, C3.2, C4.2, C5.1, C6.1, C7.1, C8.1, C9.2, C10.2, C11.2, C12.2, D1.C, R9.2, U1.3 (GND), U$2.12B (GND), U$2.12C (AGND)
IRQE: IRQ.1, U$2.5B (!IRQ)
IRQ_H: Q3.3 (D), R11.1, U1.2 (ALERT)
IRQ_L: IRQ.2, Q3.2 (S), R8.1
unnamed: D1.A, R1.1
SCL_H: Q2.3 (D), R6.1, U1.10 (SCL)
SCL_L: Q2.2 (S), R7.1, U$2.9C (SCL)
SDA_H: Q1.3 (D), R4.1, U1.9 (SDA)
SDA_L: Q1.2 (S), R5.1, U$2.10C (SDA)
VCC: AI1.3, AI2.3, AI3.3, AI4.3, C2.1, C4.1, C7.2, C8.2, C9.1, C11.1, J1.2, R1.2, R4.2, R6.2, R10.1, R11.2, U1.8 (VDD)

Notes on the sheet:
thingSoC Reference Design Open Source Sockets for IoT
Default I²C Address = 1001000

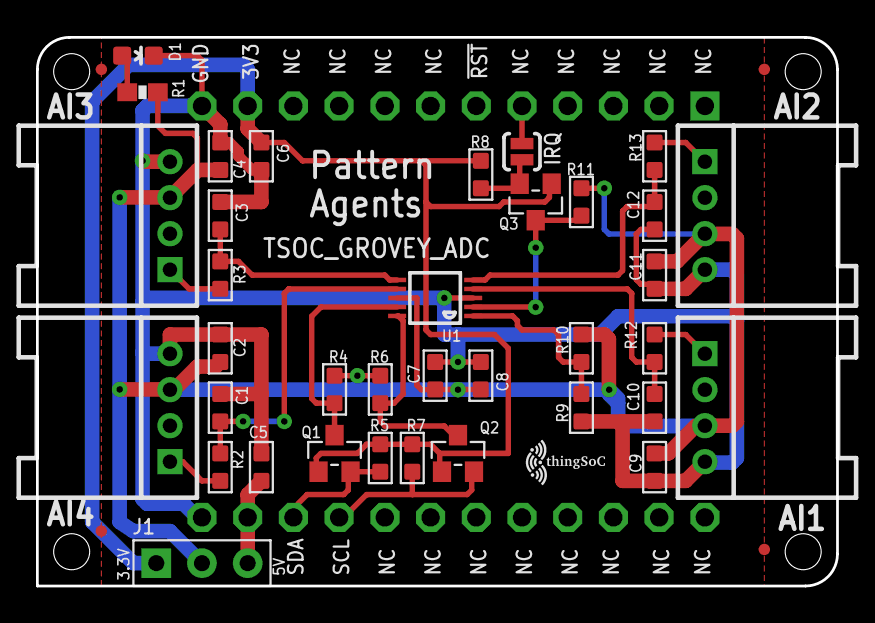
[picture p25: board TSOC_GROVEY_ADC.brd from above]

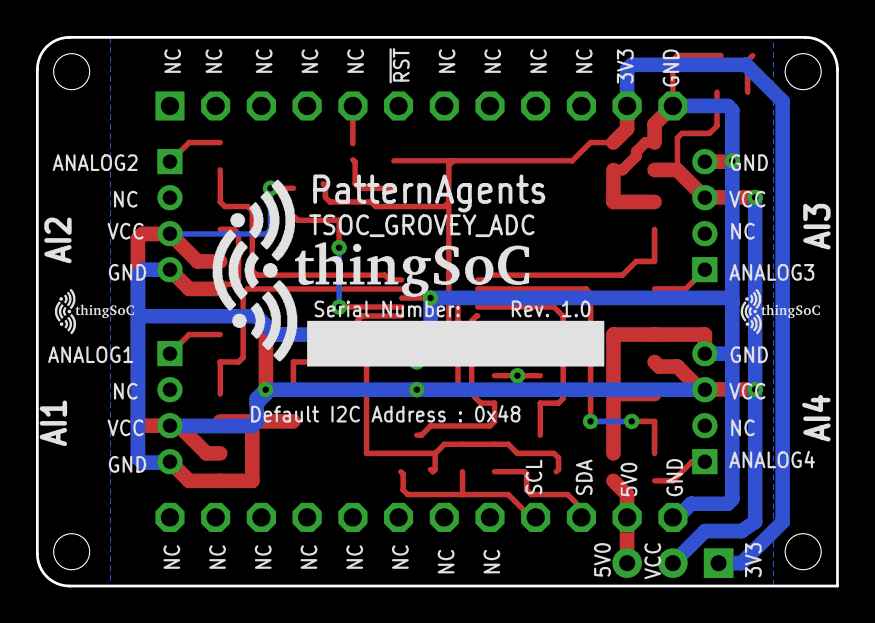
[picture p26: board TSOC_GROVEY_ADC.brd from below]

Board: 2 copper layers, 44.5 x 30.5 mm, 46 parts (3 on the bottom side), 21 nets.

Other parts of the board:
U$101: TSOC-LOGO-SMALL; TSOC-LOGO-SML

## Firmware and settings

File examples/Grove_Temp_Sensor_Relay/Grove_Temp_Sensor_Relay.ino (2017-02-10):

// Demo code for Grove - Temperature Sensor V1.1/1.2

#include <math.h>
#include <Wire.h>
#include <Adafruit_ADS1015.h>
#include <SeeedGrayOLED.h>
#include <stdlib.h>
#include <string.h>

// Adafruit_ADS1115 ads;  /* Use this for the 16-bit version */
Adafruit_ADS1015 ads;     /* Use this for the 12-bit version */

const int B = 4255;              // B value of the thermistor
const int R0 = 100000;           // R0 = 100k
const int pinTempSensor = 2;     // Grove - Temperature Sensor connect to ADC AIN1
const int pinRelay = 7;          // Grove - Temperature Sensor connect to ADC AIN1

char buf[16];
int status;

void setup()
{
//  Serial.begin(9600);
//  while (!Serial) {
//    ; // wait for serial port to connect. Needed for native USB
//  }

  pinMode(pinRelay, OUTPUT);
  digitalWrite(pinRelay, LOW);
  Wire.begin();  
  SeeedGrayOled.init();  //initialize SEEED Gray OLED display

  SeeedGrayOled.clearDisplay();           //clear the screen and set start position to top left corner
  SeeedGrayOled.setNormalDisplay();       //Set display to Normal mode
  SeeedGrayOled.setVerticalMode();        // Set to vertical mode for displaying text
  SeeedGrayOled.setGrayLevel(15); //Set Grayscale level. Any number between 0 - 15.
 
  // The ADC input range (or gain) can be changed via the following
  // functions, but be careful never to exceed VDD +0.3V max, or to
  // exceed the upper and lower limits if you adjust the input range!
  // Setting these values incorrectly may destroy your ADC!
  //                                                                ADS1015  ADS1115
  //                                                                -------  -------
  ads.setGain(GAIN_TWOTHIRDS);  // 2/3x gain +/- 6.144V  1 bit = 3mV      0.1875mV (default)
  // ads.setGain(GAIN_ONE);        // 1x gain   +/- 4.096V  1 bit = 2mV      0.125mV
  // ads.setGain(GAIN_TWO);        // 2x gain   +/- 2.048V  1 bit = 1mV      0.0625mV
  // ads.setGain(GAIN_FOUR);       // 4x gain   +/- 1.024V  1 bit = 0.5mV    0.03125mV
  // ads.setGain(GAIN_EIGHT);      // 8x gain   +/- 0.512V  1 bit = 0.25mV   0.015625mV
  // ads.setGain(GAIN_SIXTEEN);    // 16x gain  +/- 0.256V  1 bit = 0.125mV  0.0078125mV
  
  ads.begin();    
}

void loop()
{
    // int a = analogRead(pinTempSensor);
    int a = ads.readADC_SingleEnded(pinTempSensor);

    //float R = 1023.0/((float)a)-1.0;
    float R = 1689/((float)a)-1.0;
    R = 100000.0*R;

    float temperature=1.0/(log(R/100000.0)/B+1/298.15)-273.15;//convert to temperature via datasheet ;

    SeeedGrayOled.setTextXY(0,0);           //Set the cursor to 0th line, 0th Column
    SeeedGrayOled.putString("Temperature");
    SeeedGrayOled.setTextXY(1,0);
    SeeedGrayOled.putString("in Celsius:");
    SeeedGrayOled.setTextXY(2,0); 
    dtostrf(temperature, 4, 2, buf);  
    SeeedGrayOled.putString(buf);
       
 //   Serial.print("Temperature in Celsius = ");
 //   Serial.println(temperature);
    if (temperature > 20){
      digitalWrite(pinRelay, HIGH);
    } else {
      digitalWrite(pinRelay, LOW);
    }
    delay(100);
}

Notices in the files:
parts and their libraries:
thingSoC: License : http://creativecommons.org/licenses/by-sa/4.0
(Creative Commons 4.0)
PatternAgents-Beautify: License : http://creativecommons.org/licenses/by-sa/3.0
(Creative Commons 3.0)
